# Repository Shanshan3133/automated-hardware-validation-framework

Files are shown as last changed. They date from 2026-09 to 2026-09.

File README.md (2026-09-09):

# Automated Hardware Validation Framework







A portfolio project combining a protected 5 V buck-converter PCB with a Python automated validation bench. It demonstrates PCB design, instrument automation, fault injection, safety interlocks, data logging, and CI-style reporting—the day-to-day concerns of hardware validation and systems-integration engineering.

> **Engineering status:** the software framework is operational. The KiCad 10 schematic passes ERC with zero violations, and the routed PCB passes DRC with zero violations and zero unconnected pads. This is still an engineering prototype, not a fabrication release: land patterns, thermal-via design, compensation, derating, enclosure constraints, and schematic/PCB parity need independent review.

## PCB preview

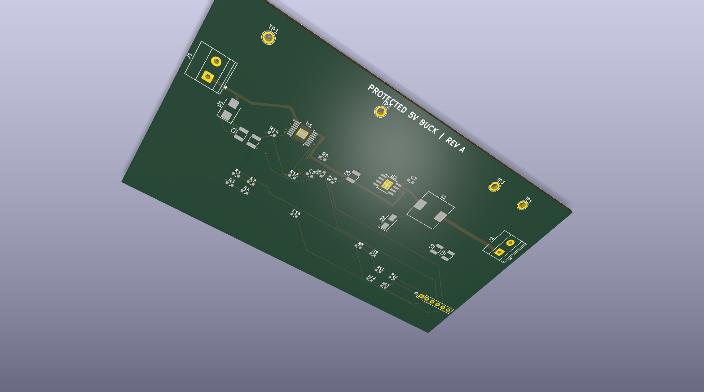
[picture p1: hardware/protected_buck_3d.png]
Rev-A protected buck PCB 3D render


## KiCad schematic

Protected 5 V buck KiCad schematic

The editable source is `hardware/protected_buck.kicad_sch`; its generated PDF is included for design review. KiCad 10.0.6 reports zero ERC errors and zero ERC warnings, and the automated parity check matches all 88 schematic pins to 88 PCB pads.

## Electrical architecture

Protected 5 V buck schematic overview

This review overview explicitly separates the TPS26600 `RTN` domain from `SYSTEM_GND`, shows the required 10 nF BOOT-to-PH capacitor, and identifies the protected DAQ signals.

The DUT uses a TPS26600 eFuse front end and a TPS5431 asynchronous buck stage. It targets 8–18 V input, regulated 5 V output, and a 1 A continuous validation load. The fixture connector exposes divided VIN/VOUT measurements, active-low fault status, shutdown control, and current-monitor signals.

## System architecture

```mermaid
flowchart LR
    PY[Python test runner] -->|SCPI / USB| PSU[Programmable supply]
    PSU --> DUT[Protected 5 V buck DUT]
    DUT --> LOAD[Electronic load]
    DUT -->|VIN and VOUT| ADC[MCP3008 ADC]
    DUT -->|FLT and SHDN| GPIO[Raspberry Pi GPIO]
    ADC --> PI[Raspberry Pi]
    GPIO --> PI
    PI --> PY
    PY --> DATA[CSV and JSON results]
    DATA --> REPORT[CI-style HTML report]
```

All test logic depends on an abstract `Bench` interface. The same suite runs against a deterministic behavioral simulator in CI or against physical SCPI instruments and Raspberry Pi I/O in the lab.

## Automated test coverage

| Test | Stimulus | Measurement | Pass criterion |
|---|---|---|---|
| Line regulation | VIN from 8 V to 18 V | VOUT | 5.0 V ±3% |
| Load regulation | Load from 0 A to 1 A | VOUT | 5.0 V ±3% |
| Output ripple | 2,000 samples at 10 MS/s | Robust Vpp | <50 mVpp |
| UVLO rising | VIN from 6 V to 9 V | Turn-on threshold | 7.1–7.9 V |
| OVP rising | VIN from 17 V to 21 V | Fault threshold | 18.4–19.6 V |
| Overcurrent trip | Load from 0.5 A to 1.8 A | Fault threshold | 1.35–1.65 A |

The MCP3008 measures DC rails and low-frequency behavior. The physical ripple test deliberately requests a 10 MS/s window through a SCPI oscilloscope adapter because a low-speed ADC cannot characterize the TPS5431's 500 kHz switching ripple. Use a bandwidth-limited scope measurement with a short ground spring and verify the scope's actual acquisition settings.

## Example validation result

```text
PASS   Line regulation: VOUT range 4.995–5.011 V
PASS   Load regulation: VOUT range 4.992–5.010 V
PASS   Output ripple: Ripple 30.3 mVpp; mean 4.993 V
PASS   UVLO rising: Turn-on detected at 7.50 V
PASS   OVP rising: Trip detected at 19.05 V
PASS   Overcurrent trip: Trip detected at 1.500 A
```

View the self-contained [HTML report with measurement plots](artifacts/report.html), [machine-readable results](artifacts/results.json), and individual CSV files in `artifacts/`.

Fault injection verifies that real specification failures are detected:

```powershell
python -m validation.cli run --backend sim --fault high-ripple --output artifacts-failing
```

This produces a failing 91.3 mVpp result and a nonzero process exit code suitable for CI gating.

## Repository layout

```text
hardware/
  protected_buck.kicad_pro      KiCad project
  protected_buck.kicad_sch      complete editable schematic; ERC clean
  protected_buck.kicad_pcb      routed two-layer PCB; DRC clean
  protected_buck.dsn/.ses       reproducible Specctra routing exchange
  protected_buck_3d.png         generated 3D preview
  protected_buck_layout.pdf     copper-layer review PDF
  protected_buck_schematic.pdf  schematic review PDF
  BOM.csv                       preliminary bill of materials
  DESIGN.md                     calculations and layout rationale
  BRINGUP.md                    controlled first-power procedure
validation/
  instruments.py                bench abstraction
  simulator.py                  deterministic behavioral DUT model
  real_bench.py                 PyVISA supply/load/scope, MCP3008, and GPIO adapters
  test_cases.py                 validation procedures and limits
  report.py                     CSV, JSON, and HTML reporting
tests/                          software unit tests
scripts/generate_board.py       reproducible KiCad PCB generator
scripts/finalize_route.py       imports routing session and finalizes reviewed nets
scripts/generate_schematic_modern.py  reproducible KiCad 10 schematic generator
scripts/check_design_parity.py  checks every schematic pin against its PCB pad net
.github/workflows/              simulated validation workflow
```

## Quick start

Simulation requires Python 3.10+ and no third-party runtime packages:

```powershell
python -m validation.cli run --backend sim --output artifacts
python -m unittest discover -s tests -v
```

Open `artifacts/report.html` after the run.

## Physical bench setup

```powershell
pip install -e ".[raspberry-pi]"
Copy-Item validation/real_bench.example.json bench.json
python -m validation.cli run --backend real --config bench.json --output artifacts-real
```

Before using the real backend:

1. Verify SCPI resource names and commands against the exact instruments.
2. Calibrate every ADC divider and verify the oscilloscope probe ratio, bandwidth limit, and channel.
3. Install an independent physical emergency-off.
4. Configure the supply limit to 2 A or less and OVP to 22 V.
5. Complete [BRINGUP.md](hardware/BRINGUP.md) with the first run attended.

The real-bench factory rejects configurations above the 2 A project safety ceiling before opening hardware resources. `safe_shutdown()` removes the electronic load and source output if a test raises an exception.

## Hardware design targets

| Characteristic | Target |
|---|---:|
| Operating input range | 8–18 V |
| Output voltage | 5.0 V ±3% |
| Validation load | 1.0 A continuous |
| Automated ripple screen | <50 mVpp |
| UVLO rising threshold | 7.5 V ±0.4 V |
| OVP rising threshold | 19.0 V ±0.6 V |
| Current-limit trip | 1.50 A ±0.15 A |

See [DESIGN.md](hardware/DESIGN.md) for calculations, [VALIDATION_STATUS.md](hardware/VALIDATION_STATUS.md) for the exact engineering status, and [ROUTING_CHECKLIST.md](hardware/ROUTING_CHECKLIST.md) for the post-routing review gates.

## Before fabrication

- Verify exposed-pad thermal-via patterns with the PCB manufacturer.
- Recheck compensation, bootstrap, current-limit mode, component derating, and fault behavior against the ordered part numbers.
- Add and mechanically validate mounting holes and enclosure clearances.
- Run schematic/PCB parity checks, inspect the autorouted geometry manually, and complete an independent engineering review.
- Assemble one prototype and complete the controlled bring-up and physical validation plan.

This repository is an engineering portfolio artifact and learning platform. It is not a certified power product or production manufacturing release.

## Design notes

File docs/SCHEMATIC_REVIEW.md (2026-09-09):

# Schematic review notes

This revision converts the most important observations from the KiCad review into explicit design constraints. The README now includes both the clean architecture diagram and the exported KiCad schematic. The editable native schematic passes ERC with zero errors and zero warnings.

## Corrected constraints

- Keep TPS26600 `RTN` separate from downstream `SYSTEM_GND`; do not replace the internal reverse-polarity path with a copper short.
- Reference UVLO, OVP, ILIM, dV/dt, MODE, and IMON programming components to `RTN`.
- Fit 10 nF from TPS5431 BOOT to PH/SW and place it at the IC pins.
- Use a 0 Ω MODE-to-RTN option for active current-limit auto-retry.
- Provide the FLT pull-up in the 3.3 V fixture domain; never pull a Raspberry Pi input to the protected power rail.
- Drive SHDN through an open-drain or isolated fixture output.
- Use the oscilloscope backend for ripple; do not claim 500 kHz ripple performance from a 10 kS/s ADC.

## Release gate

The KiCad source remains an engineering prototype. ERC, DRC, and connectivity gates are clean. Before fabrication, verify land patterns and exact ordered parts, complete schematic/PCB parity, review thermal and mechanical design, and obtain an independent engineering review.

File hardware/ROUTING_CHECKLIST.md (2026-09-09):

# PCB Post-routing Review Checklist

The board now includes all footprints, named nets, a bottom ground plane, completed routing, test points, and the DAQ connector. KiCad 10.0.6 reports zero DRC violations and zero unconnected pads. The items below are engineering release gates, not missing ratsnest connections.

## Review in KiCad before fabrication

1. Minimize the U2–D2–L1–C8/C9 switching-current loops.
2. Confirm the R8/R9 Kelvin feedback path samples at the output capacitors and stays away from SW.
3. Confirm both ADC dividers, J3 pin order, and the 3.3 V maximum at every Raspberry Pi-facing signal.
4. Verify that TPS26600 RTN remains isolated from system GND through the intended device path.
5. Design and review the exposed-pad thermal-via arrays; check annular ring and drill limits with the selected manufacturer.
6. Add four M3 mounting holes and verify connector orientation and keep-outs against the enclosure.
7. Refill copper, rerun DRC, and preserve zero violations and zero unconnected items after every change.
8. Run schematic/PCB parity and inspect every autorouted neck-down, via, return path, and high-current segment manually.
9. Have another engineer review polarity, ratings, mode pins, protection behavior, creepage, and test-point access.

## Why this is not yet a fabrication release

Connectivity and automated rule checks are complete. TPS26600 configuration, TPS5431 compensation/bootstrap details, thermal-via design, land patterns, enclosure constraints, and final component derating still require review against the exact ordered parts.

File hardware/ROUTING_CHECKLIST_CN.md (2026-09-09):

# PCB完成清单

当前板已经完成全部网络布线。KiCad 10.0.6检查结果：DRC违规0项，未连接焊盘0项。以下内容是打板前的工程审查门槛，不是剩余飞线。

## 在KiCad中完成打板前审查

1. 打开`protected_buck.kicad_pro`和PCB编辑器。
2. 优先缩短U2、D2、L1、C8/C9组成的开关电流回路。
3. 确认R8/R9从输出电容处做Kelvin采样，并远离SW节点。
4. 复核VIN/VOUT ADC分压器、J3引脚顺序，以及所有树莓派信号不超过3.3V。
5. 保持TPS26600的RTN与系统GND通过器件内部预期路径隔离。
6. 为U1和U2裸露焊盘设计并复核散热过孔阵列，确认板厂孔径和环宽能力。
7. 增加四个M3安装孔，并确认连接器方向、外壳和禁布区。
8. 每次修改后重新铺铜和运行DRC，保持“违规0项、未连接0项”。
9. 运行原理图/PCB一致性检查，并逐条人工检查自动布线的线宽收缩、过孔、回流路径和大电流走线。
10. 打板前由另一名工程师复核极性、额定值、模式脚、保护动作、爬电距离和测试点可达性。

## 当前不得直接打板的原因

连通性和自动规则检查已经完成，但TPS26600配置、TPS5431补偿/自举细节、散热过孔、封装、外壳约束和最终器件降额仍需依据实际采购料号复核。

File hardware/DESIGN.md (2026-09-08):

# Protected buck design notes

## Power path

J1 feeds TVS D1 and TPS26600 eFuse U1. U1 provides reverse-polarity protection, adjustable UVLO/OVP, inrush control, current limiting, and an active-low fault output. Its protected output feeds TPS5431 U2, configured as a 5 V asynchronous buck using L1, D2, and C8/C9. J2 is the load output; J3 exposes divided VIN/VOUT sense, protected FLT, shutdown, current monitor, and system ground to the Raspberry Pi fixture.

`RTN` and `GND` are deliberately different nets. J1 return, the input TVS/capacitors, U1 exposed pad, and the UVLO/OVP/ILIM/dVdT/MODE/IMON programming parts use `RTN`. U1 pin 9 is the downstream system ground. They must not be shorted on the PCB because the TPS26600 reverse-polarity protection element sits between them.

## First-pass calculations

TPS26600 adjustable UVLO/OVP comparators are nominally 1.19 V. Divider threshold is approximately `VTRIP = 1.19 × (RTOP + RBOT) / RBOT`.

- UVLO: 52.3 kΩ / 10 kΩ → 7.41 V nominal.
- OVP: 150 kΩ / 10 kΩ → 19.04 V nominal.
- ILIM: 8.06 kΩ corresponds to approximately 1.5 A from the datasheet characterization.
- MODE: R14 = 0 Ω to RTN selects active current limiting with auto-retry.
- IMON: R15 = 16.9 kΩ to RTN converts the monitor current to a measurable voltage; R16 = 100 kΩ limits fault current into the fixture ADC.
- TPS5431 feedback: 1.221 V reference with 30.9 kΩ / 10 kΩ → 4.99 V nominal.
- Bootstrap: C7 = 10 nF directly between BOOT and PH/SW.

The 15 µH inductor and 2 × 47 µF output capacitance are starting values. Confirm loop stability, saturation margin, RMS ripple current, and thermal rise using the final capacitor bias curves and vendor design tools.

## Layout intent

- Keep U2–D2–L1 switching loop compact and on the top layer.
- Use a solid bottom ground plane and via-stitch both exposed pads.
- Kelvin-route FB from the output capacitor, away from SW.
- Place TVS and input ceramics at J1/U1; place output ceramics at L1/J2.
- Route DAQ sense traces separately from high-current copper and join at Kelvin points.
- Treat `FLT_DAQ` as an open-drain signal: the fixture provides the 3.3 V pull-up. Drive `SHDN` only through an open-drain or isolated output.
- Measure switching ripple with a bandwidth-limited oscilloscope and short ground spring; the MCP3008 is for DC and low-frequency monitoring only.

## Review gates before fabrication

1. Replace any generic footprints with verified manufacturer land patterns.
2. Run KiCad ERC/DRC and resolve every warning intentionally.
3. Verify the TPS26600 RTN/GND boundary, MODE, IMON and dV/dt networks, plus the TPS5431 bootstrap network and both exposed-pad connections against the current datasheets.
4. Validate creepage, copper width, via current, component derating, and enclosure constraints.
5. Have another engineer review the schematic and layout.

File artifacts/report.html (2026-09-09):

# Hardware Validation Report

PWR-5V Protected Buck Rev A

PASS6/6 tests passed

Test | Status | Result | Time
Line regulation | PASS | VOUT range 4.995–5.011 V | 0.000s
Load regulation | PASS | VOUT range 4.992–5.010 V | 0.000s
Output ripple | PASS | Ripple 30.3 mVpp; mean 4.993 V | 0.003s
UVLO rising | PASS | Turn-on detected at 7.50 V | 0.000s
OVP rising | PASS | Trip detected at 19.05 V | 0.000s
Overcurrent trip | PASS | Trip detected at 1.500 A | 0.000s

## Measurement plots

### Line regulation

PASS

VOUT range 4.995–5.011 V

### Load regulation

PASS

VOUT range 4.992–5.010 V

### Output ripple

PASS

Ripple 30.3 mVpp; mean 4.993 V

### UVLO rising

PASS

Turn-on detected at 7.50 V

### OVP rising

PASS

Trip detected at 19.05 V

### Overcurrent trip

PASS

Trip detected at 1.500 A

## Run metadata

dut

PWR-5V Protected Buck Rev A

backend

sim

seed

7

fault_injection

none

host

386278Mss

python

3.13.3

generated_utc

2026-09-09T13:17:25+00:00

Raw measurements and machine-readable results are stored beside this report.

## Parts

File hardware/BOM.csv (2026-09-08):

Reference | Qty | Value | Description | Footprint
U1 | 1 | TPS26600PWPR | 60 V 2 A eFuse with UVLO OVP ILIM | Package_SO:HTSSOP-16-1EP_4.4x5mm_P0.65mm
U2 | 1 | TPS5431DDA | 23 V 3 A 500 kHz asynchronous buck | Package_SO:TI_SO-PowerPAD-8_ThermalVias
D1 | 1 | SMBJ24A | Input transient suppressor | Diode_SMD:D_SMB
D2 | 1 | B340A | 3 A 40 V Schottky catch diode | Diode_SMD:D_SMA
L1 | 1 | 15uH 4A | Shielded power inductor | Inductor_SMD:L_10.4x10.4_H4.8
C1 C2 | 2 | 10uF 50V | Input ceramic capacitor | Capacitor_SMD:C_1210_3225Metric
C5 | 1 | 22nF | eFuse output slew control to RTN | Capacitor_SMD:C_0603_1608Metric
C6 | 1 | 10uF 50V | Protected-input ceramic capacitor | Capacitor_SMD:C_1210_3225Metric
C7 | 1 | 10nF | TPS5431 BOOT-to-PH bootstrap capacitor | Capacitor_SMD:C_0603_1608Metric
C8 C9 | 2 | 47uF 10V | Output ceramic capacitor | Capacitor_SMD:C_1210_3225Metric
R1 | 1 | 52.3k 1% | UVLO divider upper | Resistor_SMD:R_0603_1608Metric
R2 | 1 | 10k 1% | UVLO divider lower to RTN | Resistor_SMD:R_0603_1608Metric
R3 | 1 | 150k 1% | OVP divider upper | Resistor_SMD:R_0603_1608Metric
R4 | 1 | 10k 1% | OVP divider lower to RTN | Resistor_SMD:R_0603_1608Metric
R5 | 1 | 8.06k 1% | Approximately 1.5 A eFuse limit | Resistor_SMD:R_0603_1608Metric
R6 | 1 | 1k | FLT series protection; fixture provides 3.3 V pull-up | Resistor_SMD:R_0603_1608Metric
R7 | 1 | 100k | SHDN fail-safe pull-up; drive with open drain | Resistor_SMD:R_0603_1608Metric
R8 | 1 | 30.9k 1% | 5 V feedback upper | Resistor_SMD:R_0603_1608Metric
R9 | 1 | 10k 1% | 5 V feedback lower | Resistor_SMD:R_0603_1608Metric
R14 | 1 | 0R | MODE to RTN for current-limit auto-retry | Resistor_SMD:R_0603_1608Metric
R15 | 1 | 16.9k 1% | IMON programming resistor to RTN | Resistor_SMD:R_0603_1608Metric
R16 | 1 | 100k | IMON ADC fault-current limiting series resistor | Resistor_SMD:R_0603_1608Metric
J1 J2 | 2 | 2-pin 5.08mm | Power terminal block | TerminalBlock_Phoenix:TerminalBlock_Phoenix_MKDS-1 | 5-2_1x02_P5.00mm_Horizontal
J3 | 1 | 1x06 | DAQ header: GND VIN_SENSE VOUT_SENSE FLT_DAQ SHDN IMON_DAQ | Connector_PinHeader_2.54mm:PinHeader_1x06_P2.54mm_Vertical
TP1 TP2 TP3 TP4 | 4 | Test point | VIN PROTECTED_IN VOUT GND | TestPoint:TestPoint_Plated_Hole_D2.0mm
R10 R11 | 2 | 56k / 10k 1% | VIN ADC divider | Resistor_SMD:R_0603_1608Metric
R12 R13 | 2 | 10k / 15k 1% | VOUT ADC divider | Resistor_SMD:R_0603_1608Metric

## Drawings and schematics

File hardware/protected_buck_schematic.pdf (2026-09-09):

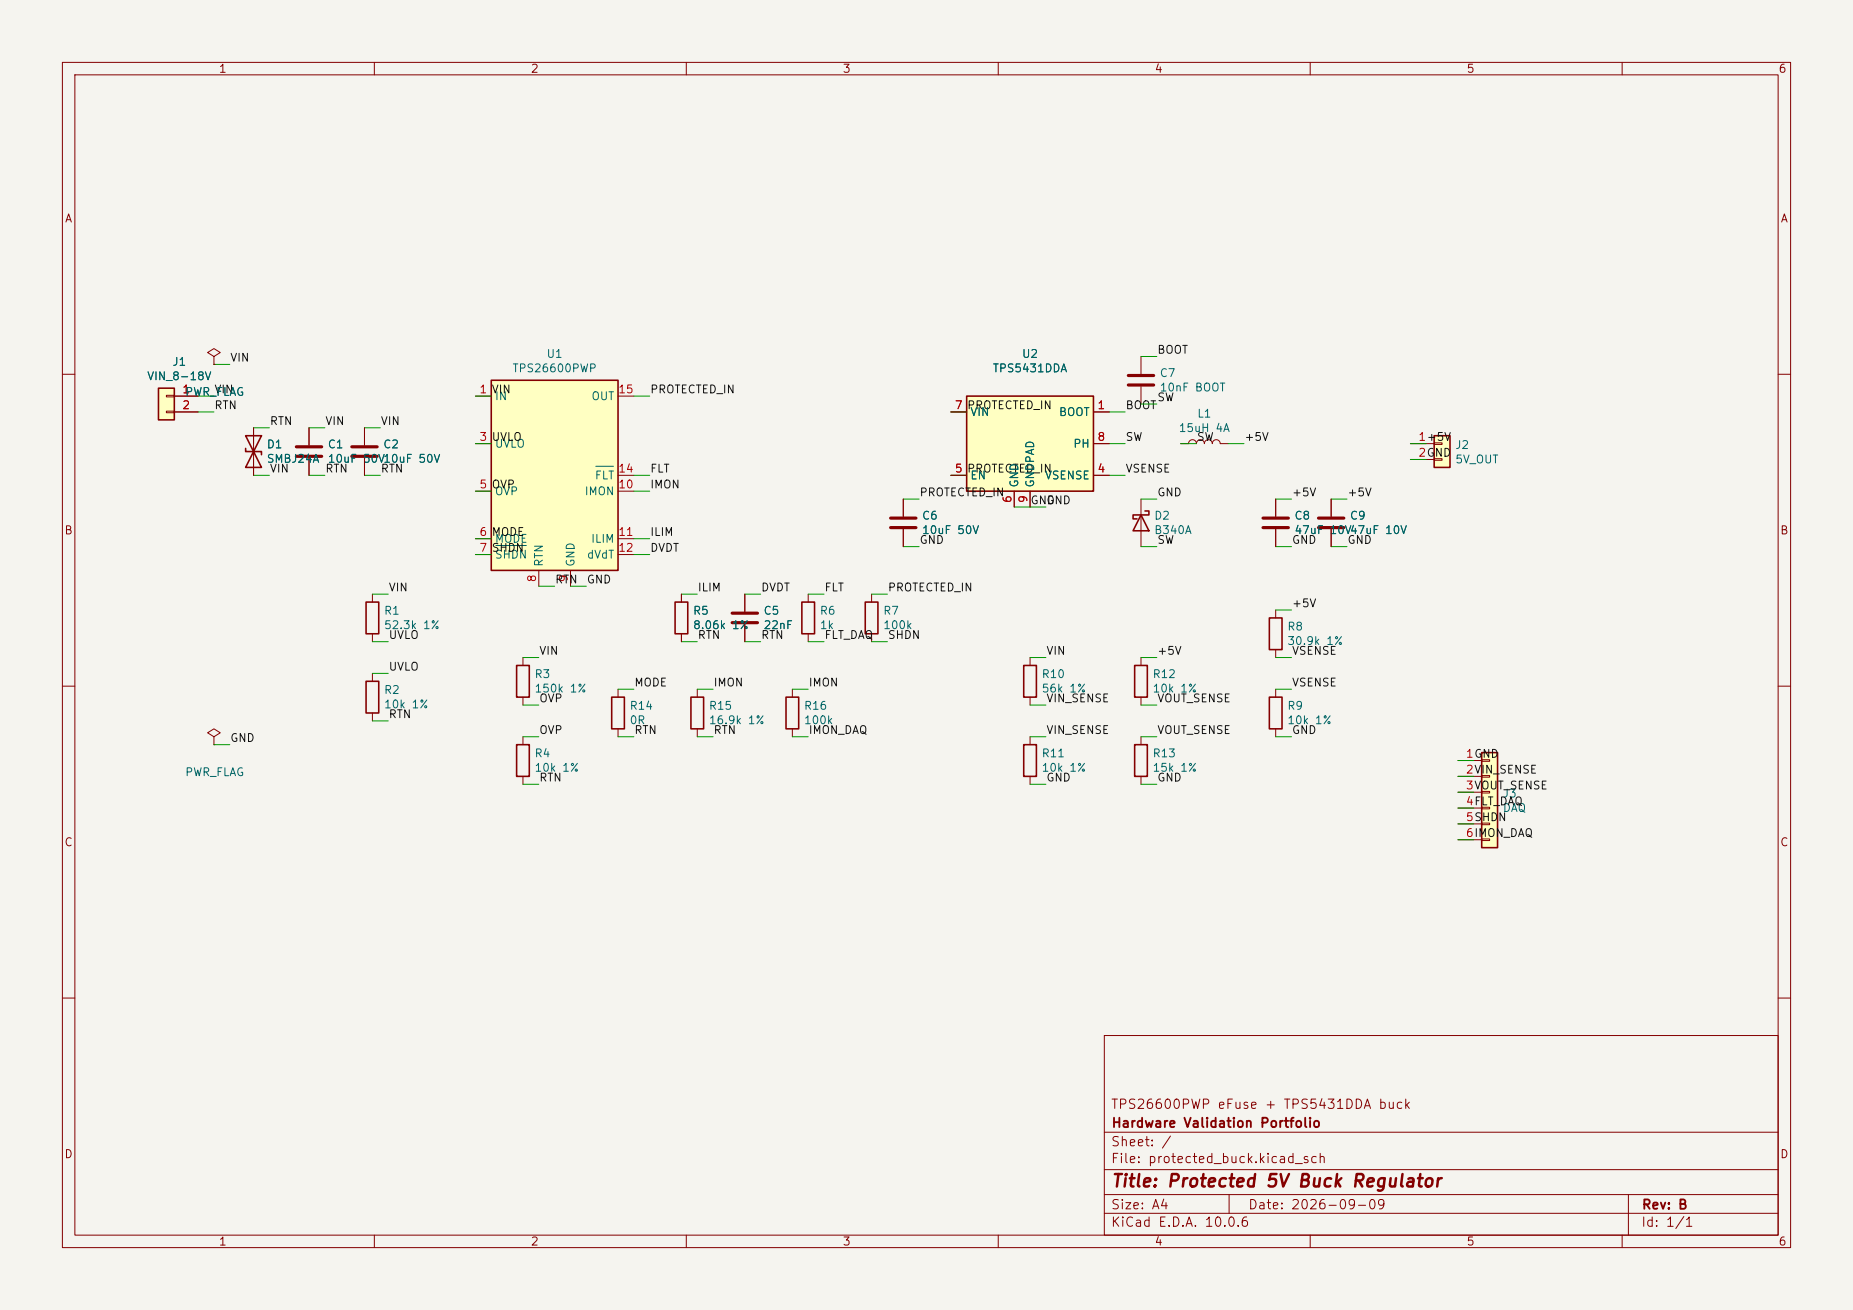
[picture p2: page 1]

Hardware Validation Portfolio
Sheet: /
File: protected_buck.kicad_sch
Title: Protected 5V Buck Regulator

Size: A4 | Rev: B
KiCad E.D.A. 10.0.6 | Id: 1/1

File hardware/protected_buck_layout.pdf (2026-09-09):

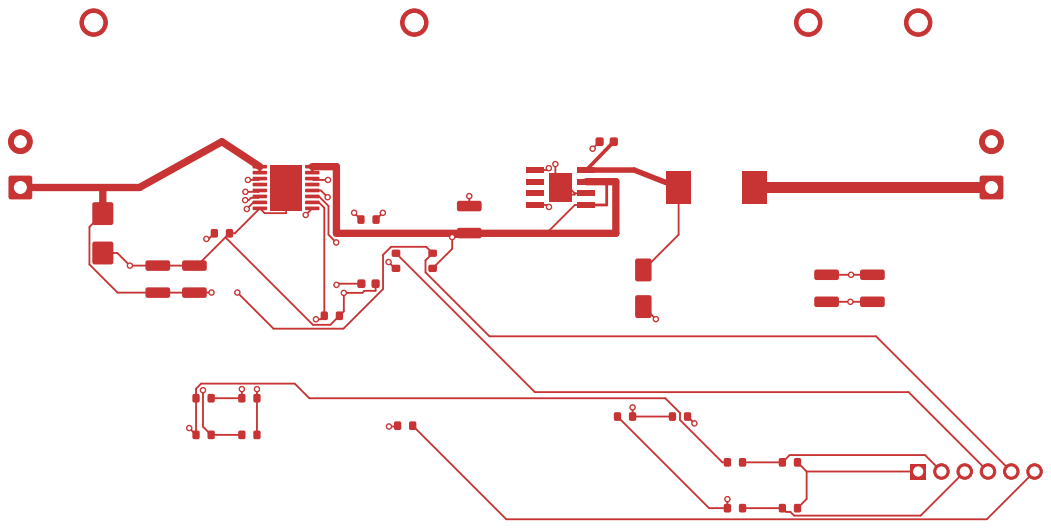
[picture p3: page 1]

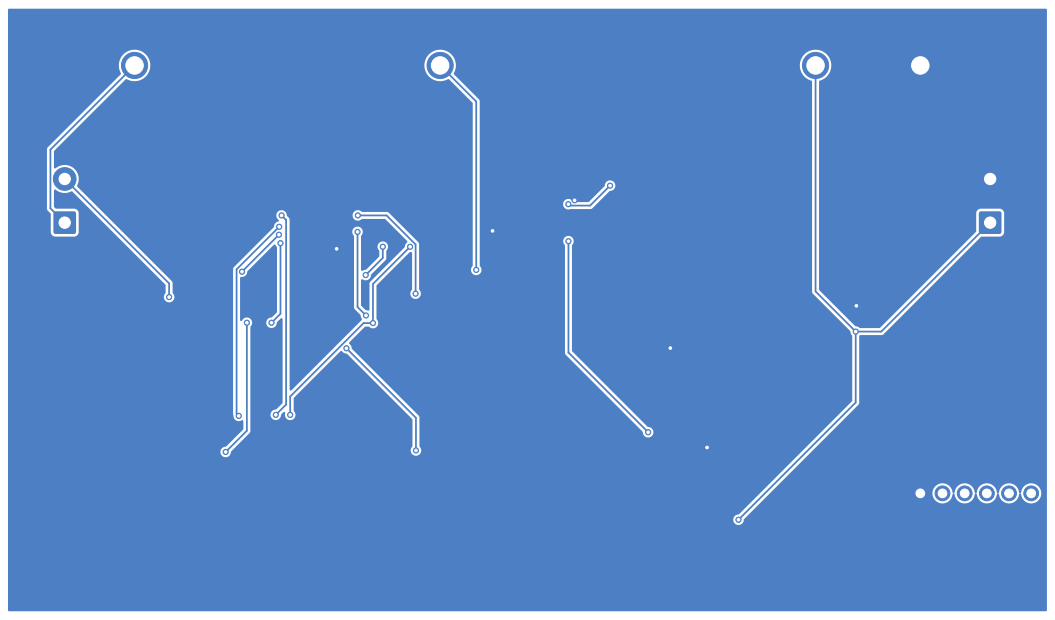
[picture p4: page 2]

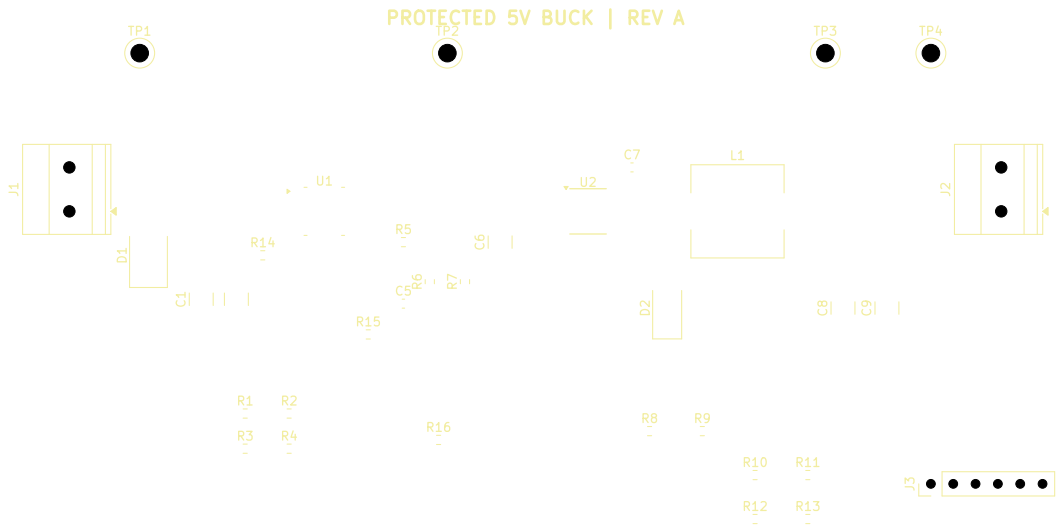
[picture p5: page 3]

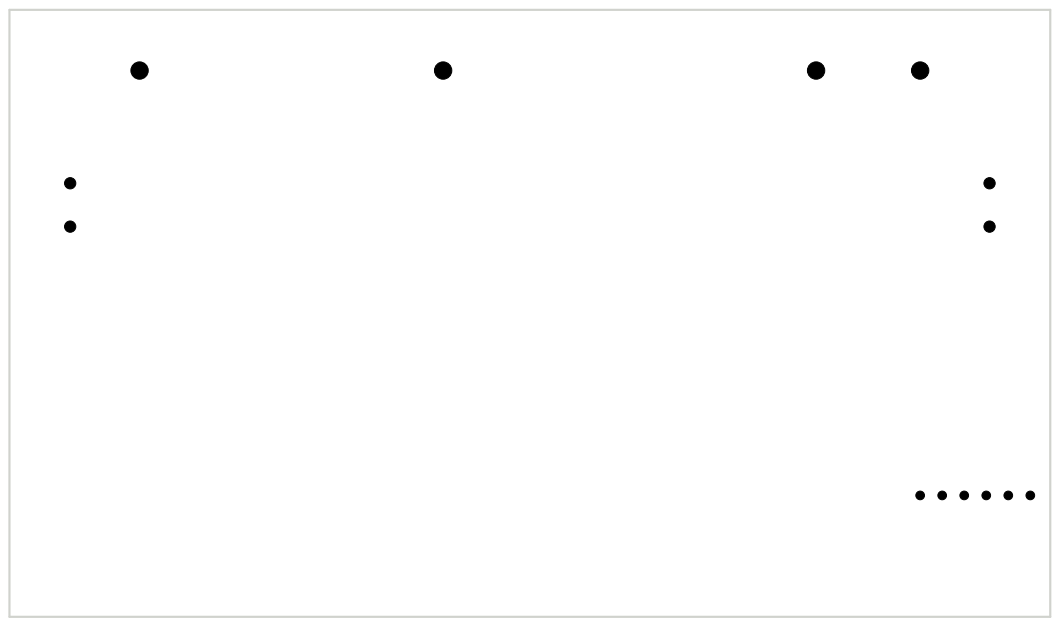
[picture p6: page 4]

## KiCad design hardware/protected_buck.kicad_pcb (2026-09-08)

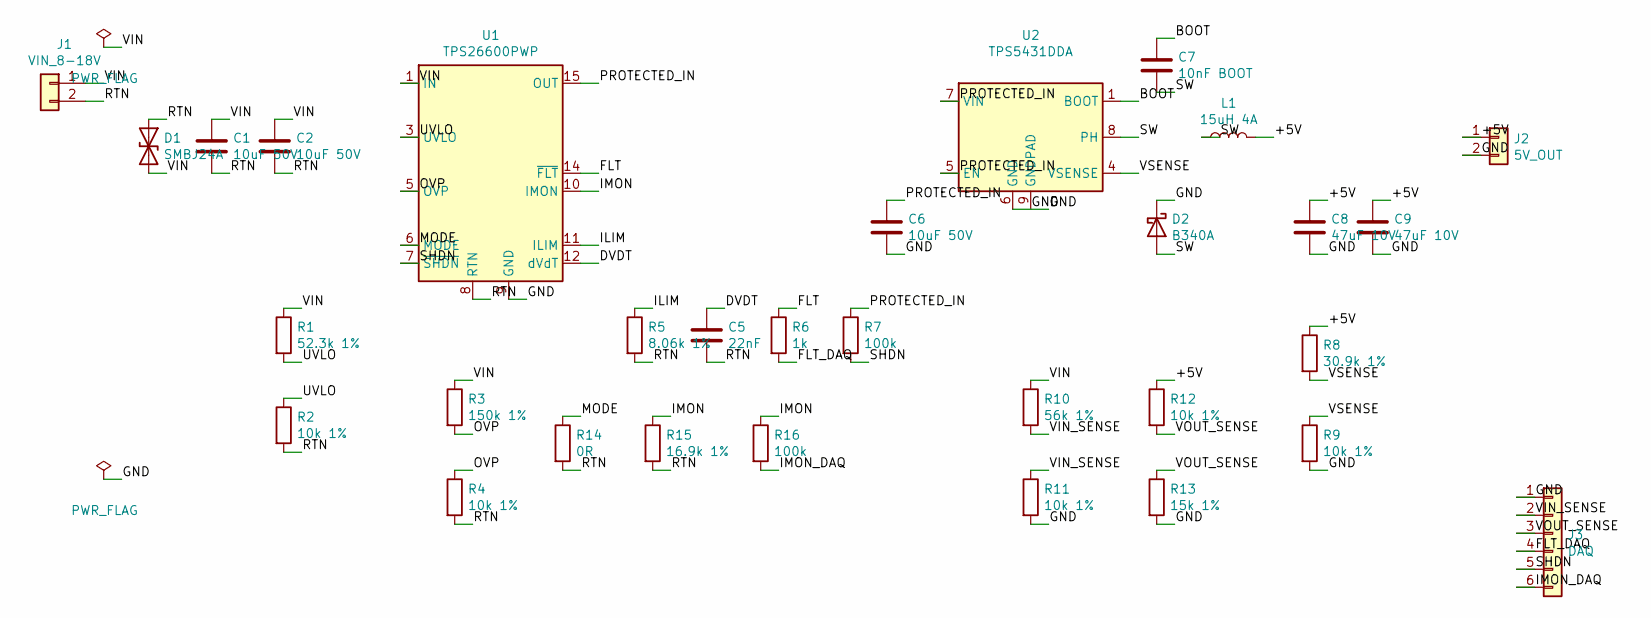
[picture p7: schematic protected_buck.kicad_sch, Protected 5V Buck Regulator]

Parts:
C1, C2, C6: 10uF 50V; C_1210_3225Metric
C5: 22nF; C_0603_1608Metric
C7: 10nF BOOT; C_0603_1608Metric
C8, C9: 47uF 10V; C_1210_3225Metric
D1: SMBJ24A; D_SMB
D2: B340A; D_SMA
J1: VIN_8-18V; TerminalBlock_Phoenix_MKDS-1,5-2_1x02_P5.00mm_Horizontal
J2: 5V_OUT; TerminalBlock_Phoenix_MKDS-1,5-2_1x02_P5.00mm_Horizontal
J3: DAQ; PinHeader_1x06_P2.54mm_Vertical
L1: 15uH 4A; L_10.4x10.4_H4.8
R1: 52.3k 1%; R_0603_1608Metric
R2, R4, R9, R11, R12: 10k 1%; R_0603_1608Metric
R3: 150k 1%; R_0603_1608Metric
R5: 8.06k 1%; R_0603_1608Metric
R6: 1k; R_0603_1608Metric
R7, R16: 100k; R_0603_1608Metric
R8: 30.9k 1%; R_0603_1608Metric
R10: 56k 1%; R_0603_1608Metric
R13: 15k 1%; R_0603_1608Metric
R14: 0R; R_0603_1608Metric
R15: 16.9k 1%; R_0603_1608Metric
U1: TPS26600PWP; HTSSOP-16-1EP_4.4x5mm_P0.65mm_EP3.4x5mm_Mask2.66x2.46mm
U2: TPS5431DDA; TI_SO-PowerPAD-8

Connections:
+5V: C8.1, C9.1, J2.1, L1.2, R8.1, R12.1; also elsewhere on the board
BOOT: C7.1, U2.1 (BOOT)
DVDT: C5.1, U1.12 (dVdT)
FLT: R6.1, U1.14 (~FLT)
FLT_DAQ: J3.4, R6.2
GND: C6.2, C8.2, C9.2, D2.1 (K), J2.2, J3.1, R9.2, R11.2, R13.2, U1.9 (GND), U2.6 (GND), U2.9 (GNDPAD); also elsewhere on the board
ILIM: R5.1, U1.11 (ILIM)
IMON: R15.1, R16.1, U1.10 (IMON)
IMON_DAQ: J3.6, R16.2
MODE: R14.1, U1.6 (MODE)
OVP: R3.2, R4.1, U1.5 (OVP)
PROTECTED_IN: C6.1, R7.1, U1.15 (OUT), U1.16 (OUT), U2.5 (EN), U2.7 (VIN); also elsewhere on the board
RTN: C1.2, C2.2, C5.2, D1.1 (A1), J1.2, R2.2, R4.2, R5.2, R14.2, R15.2, U1.8 (RTN), U1.17 (RTN)
SHDN: J3.5, R7.2, U1.7 (~SHDN)
SW: C7.2, D2.2 (A), L1.1, U2.8 (PH)
UVLO: R1.2, R2.1, U1.3 (UVLO)
VIN: C1.1, C2.1, D1.2 (A2), J1.1, R1.1, R3.1, R10.1, U1.1 (IN), U1.2 (IN); also elsewhere on the board
VIN_SENSE: J3.2, R10.2, R11.1
VOUT_SENSE: J3.3, R12.2, R13.1
VSENSE: R8.2, R9.1, U2.4 (VSENSE)

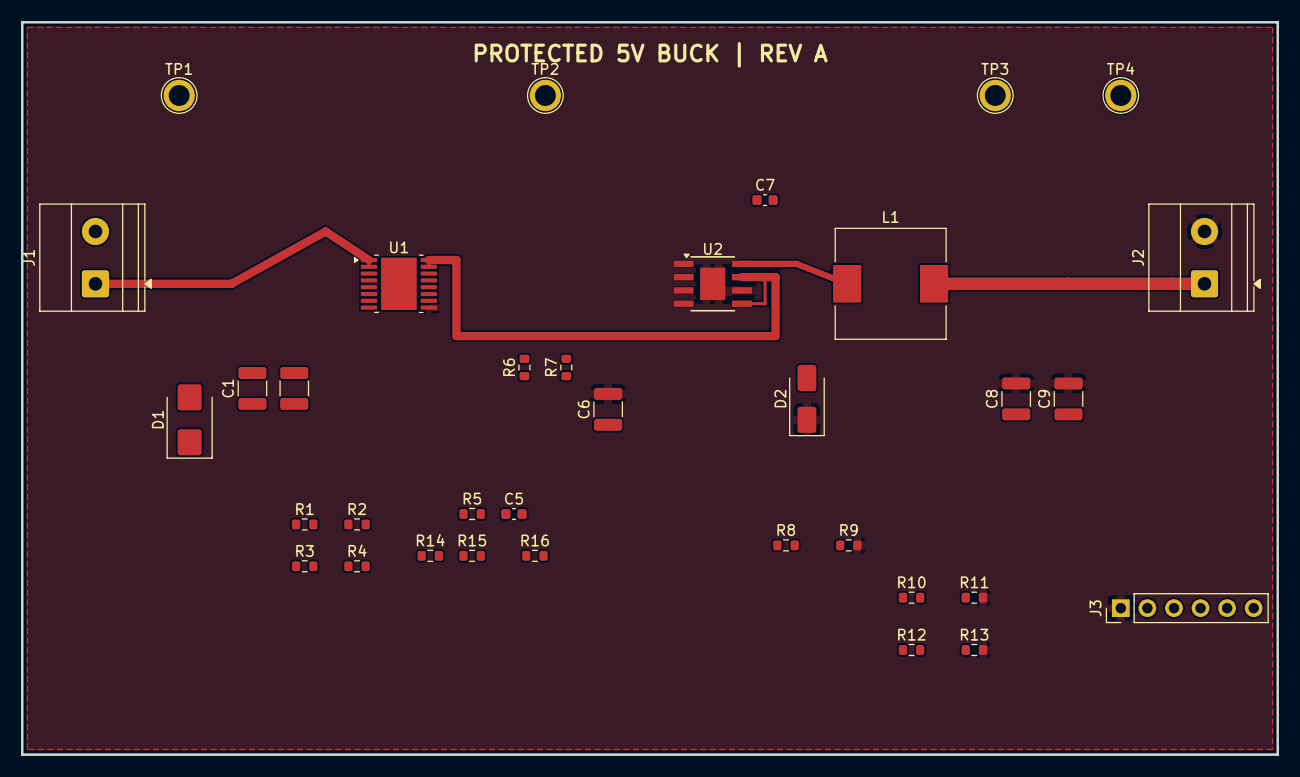
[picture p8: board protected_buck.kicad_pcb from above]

Board: 2 copper layers, 120.0 x 70.0 mm, 35 parts (0 on the bottom side), 20 nets.

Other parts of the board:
TP1: VIN; TestPoint_Plated_Hole_D2.0mm
TP2: PROTECTED_IN; TestPoint_Plated_Hole_D2.0mm
TP3: +5V; TestPoint_Plated_Hole_D2.0mm
TP4: GND; TestPoint_Plated_Hole_D2.0mm

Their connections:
+5V: TP3.1; also elsewhere on the board
GND: TP4.1; also elsewhere on the board
PROTECTED_IN: TP2.1; also elsewhere on the board
VIN: TP1.1; also elsewhere on the board

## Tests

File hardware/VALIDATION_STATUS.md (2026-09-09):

# Engineering Validation Status

Generated: September 9, 2026
Tools: KiCad 10.0.6 and Python 3.13

| Area | Result | Evidence |
|---|---|---|
| PCB parsing | Pass | KiCad CLI loads and saves the board |
| PCB DRC | Pass | Zero violations in `verification/pcb-drc-kicad-10.0.6.txt` |
| PCB connectivity | Pass | Zero unconnected pads in the same KiCad report |
| PCB 3D render | Pass | `protected_buck_3d.png` generated successfully |
| PCB layer PDF | Pass | `protected_buck_layout.pdf` generated successfully |
| Schematic format | Pass | Native KiCad 10 `.kicad_sch` source is present and reproducible |
| Schematic ERC | Pass | Zero errors and zero warnings in `verification/erc-kicad-10.0.6.txt` |
| Schematic/PCB parity | Pass | 88 schematic pins match 88 PCB pads with `scripts/check_design_parity.py` |
| Python unit tests | Pass | Five tests cover simulation, reporting, scope capture, fault injection, and current-limit safety |
| Simulated validation | Pass | Six of six validation procedures pass |
| HTML evidence | Pass | CI-style report includes measurement tables and inline SVG plots |
| Physical validation | Not run | Requires assembled hardware and calibrated lab equipment |

The electronic connectivity gates are now clean, but this is not a production release. Fabrication outputs remain gated on footprint verification, thermal-via design, compensation and derating review, mounting/enclosure checks, schematic/PCB parity, and an independent layout review.

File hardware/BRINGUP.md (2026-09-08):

# Bring-up and bench safety

1. Inspect polarity, solder bridges, exposed pads, and connector pinout with power disconnected.
2. Check resistance from VIN to GND and VOUT to GND. Investigate unexpected low resistance.
3. Use a current-limited supply at 8 V and 100 mA with no load. Confirm no heating.
4. Raise the limit gradually, verify 5 V output, then test with a power resistor before connecting the automated fixture.
5. Configure the supply hardware OVP at 22 V and current limit at 2 A. Add a physical emergency-off that removes DUT power independently of Python.
6. Calibrate ADC channels against a traceable DMM. Record gain/offset and fixture revision.
7. Only then run threshold sweeps. Keep the first run attended and use thermal monitoring.

The low-cost ADC ripple result is a screening measurement, not a substitute for a bandwidth-limited oscilloscope measurement with a short ground spring.

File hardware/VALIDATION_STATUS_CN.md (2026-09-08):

# 工程验证状态

生成日期：2026-09-08  
验证工具：KiCad 10.0.6、Python 3.13

| 项目 | 结果 | 说明 |
|---|---|---|
| PCB文件解析 | 通过 | KiCad CLI可加载和保存 |
| PCB几何DRC | 通过 | 0条短路、间距、交叉或丝印违规 |
| PCB网络完整性 | 未通过 | 36个未连接项目，属于待布小信号和支路 |
| PCB 3D渲染 | 通过 | 已生成`protected_buck_3d.png` |
| PCB层图PDF | 通过 | 已生成`protected_buck_layout.pdf` |
| 原理图格式 | 待转换 | 当前为KiCad旧格式`.sch`，需在KiCad 10中保存为`.kicad_sch` |
| 原理图ERC | 未通过 | 旧格式连接和电源标记需要在转换后整理 |
| Python单元测试 | 通过 | 仿真、故障注入、报告和实机限流保护均覆盖 |
| 模拟验证 | 通过 | 6/6项通过 |
| 实机验证 | 未执行 | 需要PCB、可编程电源、电子负载和树莓派ADC |

这份状态表用于避免把“可打开的工程”误认为“已具备生产条件”。只有在网络完整性和ERC都通过、器件选型完成复核后才能导出Gerber。

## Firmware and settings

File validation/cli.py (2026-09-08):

from __future__ import annotations

import argparse
import json
import platform
import sys
from pathlib import Path

from .models import Status, TestResult
from .report import write_results
from .simulator import SimulatedBench
from .test_cases import all_tests


def run(args: argparse.Namespace) -> int:
    spec_path = Path(__file__).with_name("spec.json")
    spec = json.loads(spec_path.read_text(encoding="utf-8"))
    if args.backend == "sim":
        bench = SimulatedBench(seed=args.seed, fault=args.fault)
    else:
        if not args.config:
            raise SystemExit("--config is required with --backend real")
        from .real_bench import build_real_bench
        bench = build_real_bench(args.config)
    results: list[TestResult] = []
    try:
        with bench:
            results = all_tests(bench, spec)
    except Exception as exc:
        results.append(TestResult("Bench execution", Status.ERROR, f"{type(exc).__name__}: {exc}"))
    metadata = {"dut": spec["dut_name"], "backend": args.backend, "seed": args.seed,
                "fault_injection": args.fault or "none", "host": platform.node(), "python": platform.python_version()}
    report = write_results(Path(args.output), results, metadata)
    for result in results:
        print(f"{result.status.value:5}  {result.name}: {result.summary}")
    print(f"Report: {report.resolve()}")
    return 0 if results and all(r.status == Status.PASS for r in results) else 1


def main() -> int:
    parser = argparse.ArgumentParser(description="Automated protected-buck validation")
    sub = parser.add_subparsers(dest="command", required=True)
    command = sub.add_parser("run")
    command.add_argument("--backend", choices=["sim", "real"], default="sim")
    command.add_argument("--output", default="artifacts")
    command.add_argument("--seed", type=int, default=7)
    command.add_argument("--fault", choices=["high-ripple", "bad-regulation"])
    command.add_argument("--config", help="Real-bench JSON configuration")
    command.set_defaults(func=run)
    args = parser.parse_args()
    return args.func(args)


if __name__ == "__main__":
    sys.exit(main())

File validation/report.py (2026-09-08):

from __future__ import annotations

import csv
import html
import json
from datetime import datetime, timezone
from pathlib import Path

from .models import Status, TestResult


def _chart(result: TestResult) -> str:
    points = result.measurements
    if len(points) < 2:
        return ""
    stride = max(1, len(points) // 240)
    points = points[::stride]
    xs = [p.stimulus for p in points]
    ys = [p.value for p in points]
    xmin, xmax = min(xs), max(xs)
    ymin, ymax = min(ys), max(ys)
    if xmax == xmin:
        xmax = xmin + 1
    if ymax == ymin:
        ymax = ymin + 1
    pad, width, height = 34, 820, 190
    coords = []
    for x, y in zip(xs, ys):
        px = pad + (x - xmin) / (xmax - xmin) * (width - 2 * pad)
        py = height - pad - (y - ymin) / (ymax - ymin) * (height - 2 * pad)
        coords.append(f"{px:.1f},{py:.1f}")
    xunit = html.escape(points[0].stimulus_unit)
    yunit = html.escape(points[0].unit)
    trip_dots = "".join(
        f"<circle cx='{pad + (p.stimulus-xmin)/(xmax-xmin)*(width-2*pad):.1f}' "
        f"cy='{height-pad-(p.value-ymin)/(ymax-ymin)*(height-2*pad):.1f}' r='4'/>"
        for p in points if p.note == "TRIP")
    return f"""<svg class='chart' viewBox='0 0 {width} {height}' role='img' aria-label='{html.escape(result.name)} measurements'>
<line x1='{pad}' y1='{height-pad}' x2='{width-pad}' y2='{height-pad}'/><line x1='{pad}' y1='{pad}' x2='{pad}' y2='{height-pad}'/>
<polyline points='{' '.join(coords)}'/><g class='trip'>{trip_dots}</g>
<text x='{pad}' y='{height-8}'>{xmin:.3g} {xunit}</text><text x='{width-pad}' y='{height-8}' text-anchor='end'>{xmax:.3g} {xunit}</text>
<text x='4' y='{pad}'>{ymax:.4g} {yunit}</text><text x='4' y='{height-pad}'>{ymin:.4g} {yunit}</text></svg>"""


def write_results(output: Path, results: list[TestResult], metadata: dict) -> Path:
    output.mkdir(parents=True, exist_ok=True)
    for index, result in enumerate(results, 1):
        path = output / f"{index:02d}_{result.name.lower().replace(' ', '_')}.csv"
        with path.open("w", newline="", encoding="utf-8") as handle:
            writer = csv.DictWriter(handle, fieldnames=["test", "stimulus", "stimulus_unit", "value", "unit", "note"])
            writer.writeheader()
            for row in result.measurements:
                writer.writerow(row.__dict__)
    payload = {"metadata": metadata, "results": [r.to_dict() for r in results]}
    (output / "results.json").write_text(json.dumps(payload, indent=2), encoding="utf-8")
    report = output / "report.html"
    report.write_text(_html(results, metadata), encoding="utf-8")
    return report


def _html(results: list[TestResult], metadata: dict) -> str:
    passed = sum(r.status == Status.PASS for r in results)
    overall = "PASS" if passed == len(results) else "FAIL"
    generated = datetime.now(timezone.utc).isoformat(timespec="seconds")
    rows = "".join(
        f"<tr><td>{html.escape(r.name)}</td><td><span class='{r.status.value.lower()}'>{r.status.value}</span></td>"
        f"<td>{html.escape(r.summary)}</td><td>{r.duration_s:.3f}s</td></tr>" for r in results)
    meta = "".join(f"<dt>{html.escape(str(k))}</dt><dd>{html.escape(str(v))}</dd>" for k, v in metadata.items())
    charts = "".join(
        f"<article class='plot'><div><h3>{html.escape(r.name)}</h3><span class='{r.status.value.lower()}'>{r.status.value}</span></div>"
        f"<p>{html.escape(r.summary)}</p>{_chart(r)}</article>" for r in results)
    return f"""<!doctype html><html lang='en'><head><meta charset='utf-8'><meta name='viewport' content='width=device-width'>
<title>Hardware Validation Report</title><style>
:root{{--ink:#172033;--muted:#64748b;--pass:#087443;--fail:#b42318;--paper:#fff;--bg:#eef2f7}}
*{{box-sizing:border-box}}body{{margin:0;background:var(--bg);color:var(--ink);font:15px/1.5 system-ui,sans-serif}}
main{{max-width:1050px;margin:36px auto;padding:0 20px}}header,.card{{background:var(--paper);border-radius:14px;padding:26px;box-shadow:0 4px 18px #17203312;margin-bottom:18px}}
h1{{margin:0 0 6px;font-size:28px}}.sub{{color:var(--muted)}}.score{{display:flex;gap:20px;align-items:baseline;margin-top:20px}}.score strong{{font-size:42px}}.pass{{color:var(--pass);font-weight:750}}.fail,.error{{color:var(--fail);font-weight:750}}
table{{width:100%;border-collapse:collapse}}th,td{{padding:13px 10px;border-bottom:1px solid #e5eaf0;text-align:left}}th{{font-size:12px;text-transform:uppercase;color:var(--muted)}}
.plots{{display:grid;grid-template-columns:repeat(auto-fit,minmax(390px,1fr));gap:16px}}.plot{{border:1px solid #e5eaf0;border-radius:10px;padding:16px;min-width:0}}.plot>div{{display:flex;justify-content:space-between;align-items:center}}.plot h3{{margin:0}}.plot p{{color:var(--muted);margin:4px 0 10px}}.chart{{display:block;width:100%;height:auto;background:#f8fafc;border-radius:8px}}.chart line{{stroke:#94a3b8;stroke-width:1}}.chart polyline{{fill:none;stroke:#2563eb;stroke-width:2;vector-effect:non-scaling-stroke}}.chart text{{font-size:11px;fill:#64748b}}.chart .trip{{fill:#b42318}}
dl{{display:grid;grid-template-columns:max-content 1fr;gap:6px 18px}}dt{{font-weight:700}}dd{{margin:0;color:var(--muted)}}footer{{color:var(--muted);font-size:12px;text-align:center;padding:12px}}
@media(max-width:560px){{.plots{{grid-template-columns:1fr}}table{{font-size:12px}}th,td{{padding:8px 5px}}}}
</style></head><body><main><header><h1>Hardware Validation Report</h1><div class='sub'>{html.escape(str(metadata.get('dut', 'DUT')))}</div>
<div class='score'><strong class='{overall.lower()}'>{overall}</strong><span>{passed}/{len(results)} tests passed</span></div></header>
<section class='card'><table><thead><tr><th>Test</th><th>Status</th><th>Result</th><th>Time</th></tr></thead><tbody>{rows}</tbody></table></section>
<section class='card'><h2>Measurement plots</h2><div class='plots'>{charts}</div></section>
<section class='card'><h2>Run metadata</h2><dl>{meta}<dt>generated_utc</dt><dd>{generated}</dd></dl></section>
<footer>Raw measurements and machine-readable results are stored beside this report.</footer></main></body></html>"""

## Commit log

2026-09-08 Build automated hardware validation portfolio project
    [01_line_regulation.csv, 02_load_regulation.csv, 03_output_ripple.csv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]
2026-09-08 Improve hardware review and validation reporting
    [03_output_ripple.csv, BOM.csv, protected_buck.kicad_pcb]
2026-09-09 Complete routed PCB and ERC-clean schematic
    [protected_buck.dsn, protected_buck.kicad_sch, protected_buck.sch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]
